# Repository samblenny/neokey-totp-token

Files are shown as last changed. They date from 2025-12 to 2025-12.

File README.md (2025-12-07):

<!-- SPDX-License-Identifier: MIT -->
<!-- SPDX-FileCopyrightText: Copyright 2025 Sam Blenny -->
# NeoKey TOTP Token



This is a two factor authentication token to generate TOTP login codes for up
to four accounts. You can select which account by pressing a key on the 4-key
NeoKey keypad. The design is intended for desktop use in a safe location (wall
power + no worries of physical tampering) but where you do want to prevent
secrets from leaking over the network due to mis-configured cloud-sync backup
features or whatever.

Design Goals and Features:

1. Make the codes really easy to read and type, even in low light, by using a
   dimmable backlit TFT display with a relatively large font.

2. Support 4 TOTP account slots (one for each key of a 4-key NeoKey keypad).

3. The NeoPixel under the key for the currently selected account slot lights
   up. Pressing a different key switches the selected account. Pressing the
   selected key a second time puts the token in standby mode (backlight and
   NeoPixels off).

4. Store secrets in an I2C EEPROM rather than in the CLUE board's flash. This
   makes it so the secrets aren't trivially accessible to a connected computer
   as USB mass storage files. This way, they won't get accidentally sucked into
   backups, and malware would have to work harder to access them.

5. Set DS3231 RTC time from the USB serial console by opening the REPL,
   importing the `util` module, then calling `util.set_time()`.

6. Add and manage TOTP accounts in the EEPROM's database of account slots by
   using similar REPL functions (`import util` then `util.menu()`).

7. Use the token fully airgapped after initial setup by powering it from a
   phone charger and reading codes off the TFT display.

## Hardware

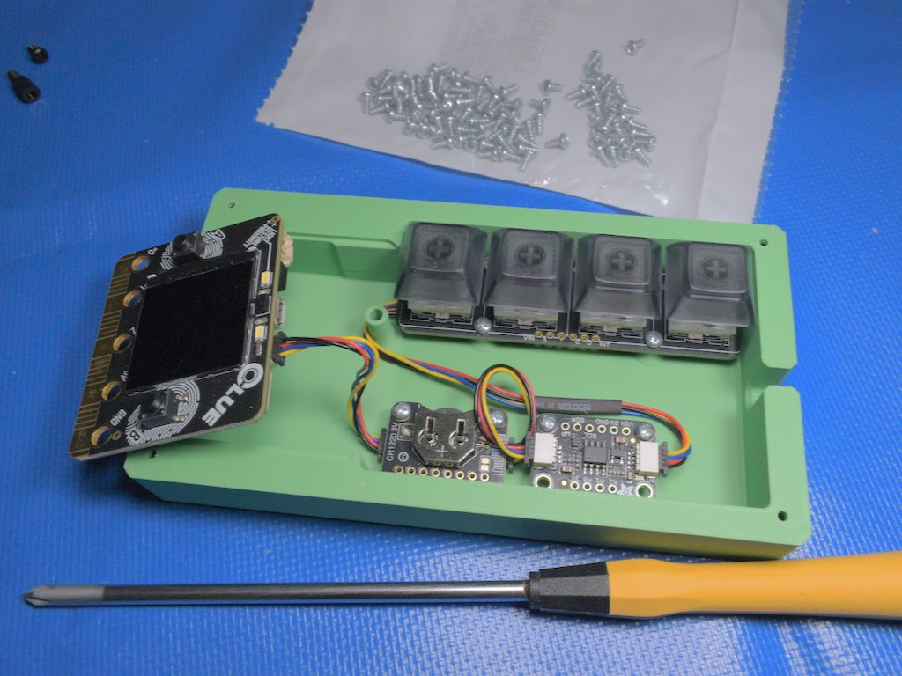
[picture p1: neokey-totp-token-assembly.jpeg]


The code here is written for:
- [Adafruit CLUE - nRF52840 Express](https://www.adafruit.com/product/4500)
- [Adafruit DS3231 Precision RTC](https://www.adafruit.com/product/5188)
- [Adafruit 24LC32 I2C EEPROM](https://www.adafruit.com/product/5146)
- [Adafruit NeoKey 1x4 QT I2C Mechanical Key Switches with NeoPixels](https://www.adafruit.com/product/4980)

Additional Parts:
- [Kailh Mechanical Key Switches Cherry MX Brown Compatible](https://www.adafruit.com/product/4954)
- [Translucent Smoke DSA Keycaps for MX Compatible Switches](https://www.adafruit.com/product/5008)
- [CR1220 3V Lithium Coin Cell Battery](https://www.adafruit.com/product/380)
- [STEMMA QT / Qwiic JST SH 4-Pin Cable - 50mm Long](https://www.adafruit.com/product/4399) (qty 2)
- [STEMMA QT / Qwiic JST SH 4-Pin Cable - 100mm Long](https://www.adafruit.com/product/4210) (qty 1)
- 2-28x3/16" Thread Rolling Screws (very short self tapping plastic screws)
- 2-28x1/4" Thread Rolling Screws (short self tapping plastic screws)

## 3D Printable Enclosure

The Blender design file and STL printable files for the enclosure are in the
[enclosure/](enclosure) directory.

To attach the I2C breakout boards to the base of the enclosure, use 2-28x3/16"
thread rolling screws. To attach the bezel to the base, use 2-28x1/4" thread
rolling screws.

## Install & Setup

You will need to:

1. Ensure your CLUE board has an [up to date bootloader](https://learn.adafruit.com/adafruit-clue/update-bootloader)

2. Download CircuitPython 10.0.3 .UF2 file from the circuitpython.org downloads
   page for
   [CLUE NRF52840 Express](https://circuitpython.org/board/clue_nrf52840_express/)

3. Follow Adafruit's
   [CircuitPython on CLUE](https://learn.adafruit.com/adafruit-clue/circuitpython)
   Learn guide to install CircuitPython: plug CLUE into a computer, double-click
   CLUE's reset button, wait for CLUEBOOT drive, drag UF2 file onto CLUEBOOT
   drive, wait for copy to finish.

4. Unplug the CLUE and assemble the rest of the hardware.

5. Get the project bundle from the release page and copy its code and library
   files from the 10.x directory to your board's `CIRCUITPY` drive.

## Set RTC Time in UTC

When you first install a battery in the DS3231, the time will be wildly wrong.
You can set the time from the REPL by importing the `util` module then calling
`util.set_time()`, like this:

```
Adafruit CircuitPython 10.0.3 on 2025-10-17; Adafruit CLUE nRF52840 Express with nRF52840
>>> import util
>>> util.now()
'2000-01-01 02:06:52'
>>> util.set_time()
Set DS3231 RTC time...
   year: 2025
  month: 11
    day: 25
   hour: 00
 minute: 01
seconds: 02
new RTC time:  2025-11-25 00:01:02
>>> # wait a while, then check the time
>>> util.get_time()
2025-11-25 00:06:02
>>>
```

When you set the time, use a GPS or NTP synchronized reference that shows UTC
time with seconds (e.g. https://samblenny.github.io/totp-util/clock/ ). Don't
set the clock according to your local timezone. You must use UTC.

Each of the "year:", "month:", "day:", etc. prompts come from python's
`input()` function. The text on the left is the input prompt shown by
`set_time()`, and the numbers on the right are an example of what you might
type for your response. When you hit return or enter for the seconds line, the
time will be set immediately.

## Store TOTP Accounts in EEPROM Database

The `util` module has several functions for managing the 4KB EEPROM as a
database of TOTP account details. You can enter QR code URIs with a 2D barcode
reader or by decoding elsewhere then copying and pasting. The EEPROM database
only stores a short (8 character) label and the 32 byte decoded seed (from the
`&secret=...` TOTP URI query parameter). The only supported options for
`&algorithm=`, `&digits=`, and `&period=` are SHA1, 6 digits, and 30 seconds.
That will work for many services that use TOTP. If you need something else, you
can modify the code.

To get started managing the EEPROM database, open the USB serial console and do
the Ctrl-C thing to get into the CircuitPython REPL. From there, import util
then call `util.menu()` to see what's available. The first time, you will need
to format the EEPROM. After that, you can add, erase, or copy accounts as you
like. There are 4 available slots (one for each key of a 4-key NeoKey keypad).

This is an example of how it looks to use the menu and provision two demo
accounts (I used a USB 2D barcode reader to type the otpauth URIs):

```
>>> import util
>>> util.menu()
Available functions:

 1. add_totp_account()    - Add a new TOTP account.
 2. copy_totp_account()   - Copy a TOTP account to another slot.
 3. erase_totp_account()  - Erase a TOTP account from EEPROM.
 4. format_eeprom()       - Format the EEPROM for TOTP storage.
 5. get_time()            - Get the current DS3231 RTC time.
 6. list_totp_accounts()  - List all stored TOTP accounts.
 7. set_time()            - Set the DS3231 RTC time.

Choose a function by number (or Enter to cancel): 4
Are you sure? This will erase all data. (y/n): y
Writing header page...
Zeroing 127 pages:
................................................................
...............................................................
EEPROM formatted successfully.
>>> util.add_totp_account()
Enter slot number (1-4): 1
Enter label (max 8 chars): Alice
Enter TOTP URI: otpauth://totp/Example:alice@google.com?secret=JBSWY3DPEHPK3PXP&issuer=Example
Record added to slot 1.
>>> util.add_totp_account()
Enter slot number (1-4): 2
Enter label (max 8 chars): JohnDoe
Enter TOTP URI: otpauth://totp/ACME%20Co:john.doe@email.com?secret=HXDMVJECJJWSRB3HWIZR4IFUGFTMXBOZ&issuer=ACME%20Co&algorithm=SHA1&digits=6&period=30
Record added to slot 2.
>>> util.list_totp_accounts()
Slot 1: 'Alice'
Slot 2: 'JohnDoe'
Slot 3: -- empty --
Slot 4: -- empty --
>>>
```

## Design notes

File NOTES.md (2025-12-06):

# Notes

Related Learn Guides:
- https://learn.adafruit.com/circuitpython-display-text-library/types-of-labels
- https://learn.adafruit.com/adafruit-ds3231-precision-rtc-breakout
- https://learn.adafruit.com/adafruit-24lc32-i2c-eeprom-breakout-32kbit-4-kb
- https://learn.adafruit.com/neokey-1x4-qt-i2c (I2C 4 key keyboard)
- https://learn.adafruit.com/adafruit-1-3-and-1-54-240-x-240-wide-angle-tft-lcd-displays
  (CLUE 1.3" 240x240 ST7789 display)
- https://learn.adafruit.com/neokey-1x4-qt-i2c

Related API Docs:
- https://docs.circuitpython.org/en/latest/shared-bindings/atexit/
- https://docs.circuitpython.org/en/latest/shared-bindings/supervisor/
- https://docs.circuitpython.org/en/latest/shared-bindings/busio/#busio.SPI
- https://docs.circuitpython.org/projects/ds3231/en/stable/api.html
- https://docs.circuitpython.org/en/latest/shared-bindings/pwmio/

RFCs:
- [RFC 4226: HOTP](https://datatracker.ietf.org/doc/html/rfc4226)
- [RFC 6238: TOTP](https://datatracker.ietf.org/doc/html/rfc6238)

Pins provided by `import board`:
```
A0              A1              A2              A3
A4              A5              A6              A7
ACCELEROMETER_GYRO_INTERRUPT    BUTTON_A        BUTTON_B
D0              D1              D10             D11
D12             D13             D14             D15
D16             D17             D18             D19
D2              D20             D3              D4
D5              D6              D7              D8
D9              DISPLAY         I2C             L
LED             MICROPHONE_CLOCK                MICROPHONE_DATA
MISO            MOSI            NEOPIXEL        P0
P1              P10             P11             P12
P13             P14             P15             P16
P17             P18             P19             P2
P20             P3              P4              P5
P6              P7              P8              P9
PROXIMITY_LIGHT_INTERRUPT       RX              SCK
SCL             SDA             SPEAKER         SPI
STEMMA_I2C      TFT_BACKLIGHT   TFT_CS          TFT_DC
TFT_MOSI        TFT_RESET       TFT_SCK         TX
UART            WHITE_LEDS
```

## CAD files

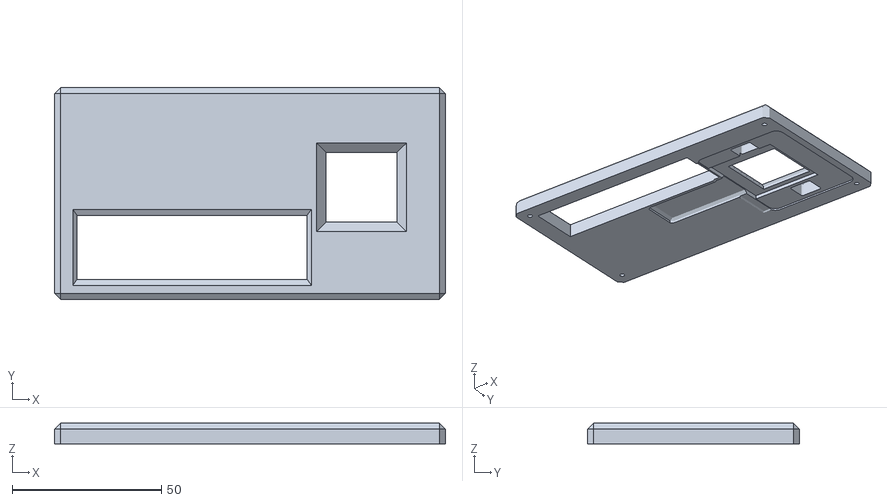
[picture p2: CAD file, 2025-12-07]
enclosure/neokey-clue-totp-bezel.stl
131.0 x 71.0 x 6.98

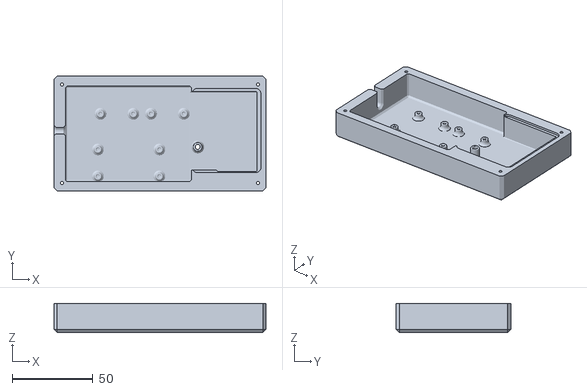
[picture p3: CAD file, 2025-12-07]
enclosure/neokey-clue-totp-base.stl
131.0 x 71.0 x 18.0

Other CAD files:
enclosure/neokey-clue-totp-nopcb.blend

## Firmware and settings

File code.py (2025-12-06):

# SPDX-License-Identifier: MIT
# SPDX-FileCopyrightText: Copyright 2025 Sam Blenny
#
# See NOTES.md for documentation links and pinout info.
#
import time

from controller import (Controller, NEOKEY0, NEOKEY1, NEOKEY2, NEOKEY3,
    NP_AMBER, NP_RED)


# The controller manages IO with I2C and SPI devices, and it keeps track of the
# EEPROM-backed database of TOTP accounts
ctrl = Controller()
ctrl.load_totp_accounts()


# These variables help with edge detection of changing values in the main loop
t = ctrl.datetime()
prev_t = t
prev_nk = ctrl.get_neokey_bits()
need_refresh = True

# Main loop
while True:

    # Is it time to update the TOTP code? (period over or refresh requested)
    if t.tm_sec % 30 == 0 or need_refresh:
        # Generate new totp code at multiples of 30 seconds
        unix_time = time.mktime(ctrl.datetime())
        slot, label, totp_code = ctrl.get_selected_totp(unix_time)
        code_changed = True

    # Redraw the display only when backlight is on
    if ctrl.bl_enable:
        seconds = t[5] % 30
        ctrl.set_text('%02d\n%s\n%s' % (seconds, label, totp_code))

    # Make sure the right NeoKey selected slot LED is lit
    for i in range(4):
        if i == ctrl.get_selected_slot():
            if ctrl.is_selected_slot_empty():
                ctrl.set_neokey(i, NP_RED)    # red for empty slots
            else:
                ctrl.set_neokey(i, NP_AMBER)  # amber for configured slots
        else:
            ctrl.set_neokey_off(i)

    # Clear the manual update requested flag
    need_refresh = False

    # Wait until second rolls over
    while t.tm_sec == prev_t.tm_sec and not need_refresh:

        # 1. Spend about 100ms polling for input events
        t_10Hz = time.monotonic() + 0.1
        while time.monotonic() < t_10Hz and not need_refresh:

            # Sleep to rate limit I2C, debounce buttons, do VM background tasks
            time.sleep(0.01)

            # Check the currently selected TOTP account slot
            slot = ctrl.get_selected_slot()

            # Monitor the 4 NeoKeys for state transitions
            nk = ctrl.get_neokey_bits()  # get bitfield of current key states
            diff = nk ^ prev_nk          # use XOR to find which bits changed
            prev_nk = nk                 # update previous values for next loop

            # Did any key get pressed while backlight was off?
            waking_up = False
            if (diff & nk) and not ctrl.bl_enable:
                # Rising edge of key press -> wake up the screen
                ctrl.backlight_on()
                need_refresh = True
                waking_up = True  # don't go back to sleep when key released

            # Check for key press to select TOTP account slots. When the
            # currently selected key is pressed, turn off the display. When a
            # different key is pressed, select the slot for that key.
            for i, bitmask in enumerate((NEOKEY0, NEOKEY1, NEOKEY2, NEOKEY3)):
                if diff & bitmask and ctrl.bl_enable:
                    # Check if other keys were already down to avoid potential
                    # weird glitchy behavior if you fat-finger multiple keys at
                    # the same time
                    other_keys_pressed = bool(nk & (~bitmask))
                    if nk & bitmask and not other_keys_pressed:
                        # Key was just pressed
                        if slot == i:
                            # Slot was already selected (toggle backlight?)
                            if not waking_up:
                                ctrl.backlight_off()
                                ctrl.set_neokey_off(i)
                        else:
                            # Slot wasn't selected -> select it
                            if ctrl.select_account(i):
                                # Selected a non-empty slot
                                ctrl.set_neokey(i, NP_AMBER)
                                need_refresh = True
                            else:
                                # Empty slot
                                ctrl.set_neokey(i, NP_RED)
                                need_refresh = True
                    else:
                        # Key released or other keys were already pressed
                        pass

            # -- END of input polling loop --


        # 2. Poll RTC at about 10 Hz to detect when seconds have changed
        if ctrl.bl_enable:
            t = ctrl.datetime()

    # After the seconds have changed, update the previous time
    prev_t = t

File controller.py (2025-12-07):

# SPDX-License-Identifier: MIT
# SPDX-FileCopyrightText: Copyright 2025 Sam Blenny
#
# See NOTES.md for documentation links and pinout info.
#
import atexit
import board
import busio
import collections
import digitalio
import displayio
from fourwire import FourWire
import gc
from micropython import const
from pwmio import PWMOut
import os
import terminalio


from adafruit_24lc32 import EEPROM_I2C
from adafruit_display_text import label
from adafruit_ds3231 import DS3231
from adafruit_neokey.neokey1x4 import NeoKey1x4
from adafruit_st7789 import ST7789

from eeprom_db import check_eeprom_format, is_slot_in_use, load_totp_account
from sb_totp import base32_encode, totp_sha1


# Begin TFT backlight dimming (100% brightness is PWM duty_cycle=0xffff)
BACKLIGHT_ON = const(26214)  # 40% of 0xffff
BACKLIGHT_OFF = const(0)

# NeoKey keypress bitfield constants
NEOKEY0 = const(1)
NEOKEY1 = const(2)
NEOKEY2 = const(4)
NEOKEY3 = const(8)

# NeoKey NeoPixel color constants
NP_AMBER = const(0x202000)
NP_RED   = const(0x400000)
NP_OFF   = const(0)


class Controller:

    def __init__(self):
        # I2C RTC, EEPROM, and NeoKey
        i2c = busio.I2C(board.SCL, board.SDA, frequency=250_000)
        self.i2c = i2c
        self.rtc = DS3231(i2c)
        self.neokey = NeoKey1x4(i2c, addr=0x30)
        self.eeprom = EEPROM_I2C(i2c)
        self.accounts = []                            # TOTP account slot data
        self.selected_acct = None

        # Display backlight PWM dimming
        self.backlight = PWMOut(board.TFT_BACKLIGHT, frequency=500,
            duty_cycle=BACKLIGHT_ON)
        self.bl_enable = True

        # CLUE 240x240 ST7789 TFT Display
        displayio.release_displays()
        gc.collect()
        spi = busio.SPI(board.TFT_SCK, MOSI=board.TFT_MOSI)
        display_bus = FourWire(spi, command=board.TFT_DC,
            chip_select=board.TFT_CS, reset=board.TFT_RESET)
        display = ST7789(display_bus, width=240, height=240, rowstart=80,
            bgr=True, rotation=0, auto_refresh=False)
        group = displayio.Group()
        display.root_group = group
        display.refresh()
        textbox = label.Label(font=terminalio.FONT, scale=4, color=0xefef00)
        textbox.anchor_point = (0, 0)
        textbox.anchored_position = (16, 8)
        textbox.line_spacing = 1.25  # default is 1.25
        group.append(textbox)
        self.spi = spi
        self.display_bus = display_bus
        self.display = display
        self.group = group
        self.textbox = textbox

        # Set an atexit handler to release the display once code.py ends. This
        # is an aesthetic filter to prevent CircuitPython's supervisor from
        # hijacking the display to show noisy stuff I don't want to see.
        def atexit_shutdown_display():
            try:
                self.set_text('OFFLINE')
                displayio.release_displays()
                self.spi.deinit()
                for i in range(4):
                    self.neokey.pixels[i] = 0
            except AttributeError:
                pass
        atexit.register(atexit_shutdown_display)


    def backlight_off(self):
        self.backlight.duty_cycle = BACKLIGHT_OFF
        self.bl_enable = False
        self.set_text('')
        # Also make sure NeoKey NeoPixels are off
        for i in range(4):
            self.set_neokey_off(i)

    def backlight_on(self):
        self.backlight.duty_cycle = BACKLIGHT_ON
        self.bl_enable = True

    def set_text(self, txt):
        self.textbox.text = txt
        self.display.refresh()

    def load_totp_accounts(self):
        # Load TOTP account slot data from EEPROM database
        TOTPAccount = collections.namedtuple("TOTPAccount",
            ["slot", "label", "secret_b32"])
        try:
            eeprom = self.eeprom
            check_eeprom_format(eeprom)
            first_used_index = None
            for slot in range(1, 5):
                if is_slot_in_use(eeprom, slot):
                    label, secret_bytes = load_totp_account(eeprom, slot)
                    secret_b32 = base32_encode(secret_bytes)
                    self.accounts.append(TOTPAccount(slot, label, secret_b32))
                    if first_used_index is None:
                        first_used_index = slot-1
                else:
                    self.accounts.append(None)
            self.selected_acct = first_used_index
        except ValueError as e:
            print(e)

        # Print summary from loading the EEPROM account database
        print('Loaded data for %d TOTP account slots from EEPROM' % (
            len(self.accounts)))
        for i, a in enumerate(self.accounts):
            if a is None:
                print(" slot %d: -- empty --")
            else:
                print(" slot %d: '%s'" % (a.slot, a.label))
        if self.selected_acct is not None:
            print("Selected Slot:", self.accounts[self.selected_acct].slot)

    def select_account(self, slot):
        # Try to select requested slot (return False for empty slot)
        if (0 <= slot < len(self.accounts)):
            self.selected_acct = slot
        else:
            raise ValueError(f"slot number out of range: {slot}")

        if self.accounts[self.selected_acct] is None:
            # This slot is empty
            return False
        # Happy path: slot is configured with an account
        return True

    def get_selected_slot(self):
        return self.selected_acct

    def is_selected_slot_empty(self):
        # Return True if there's no account configured for the selected slot
        return self.accounts[self.selected_acct] is None

    def get_selected_totp(self, unix_time):
        # Get TOTP slot, label, and code for the selected account
        if self.selected_acct is None:
            return ('', '', '')
        acct = self.accounts[self.selected_acct]
        if acct is None:
            return ('', 'empty', '')
        # CAUTION! For boards that use adafruit_hashlib.hashlib for SHA1, this
        # call may take on the order of 2 seconds to finish
        code = totp_sha1(acct.secret_b32, unix_time, digits=6, period=30)
        return (acct.slot, acct.label, code)

    def datetime(self):
        return self.rtc.datetime

    def get_neokey_bits(self):
        # Convert the list of booleans from NeoKey1x4 to an integer bitfield so
        # it's easier to detect state changes using XOR and AND
        k = self.neokey.get_keys()
        return (NEOKEY0 * int(k[0]) + NEOKEY1 * int(k[1]) + NEOKEY2 * int(k[2])
            + NEOKEY3 * int(k[3]))

    def set_neokey(self, key, color):
        self.neokey.pixels[key] = color

    def set_neokey_off(self, key):
        self.neokey.pixels[key] = NP_OFF

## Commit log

2025-11-25 hand wave to toggle display backlight
    This uses the CLUE's proximity sensor to toggle the display
    backlight on the rising edge of a proximity event. If you wave your
    hand over the CLUE, it toggles the backlight. It's like magic.
    I plan to use this to enable/disable TOTP code generation.
2025-11-26 add function to copy totp account between slots
2025-11-26 refactor util.py
    This factors out repeated boilerplate for managing totp account
    slots in the eeprom database.
2025-11-28 fix TOTP refresh on backlight enable
    Make sure that the TOTP code gets refreshed immediately when the
    backlight gets turned back on after being in standby mode.
    [code.py]
2025-12-06 overhaul code for NeoKey input
    Lots of Changes:
    - Get rid of light sensor and CLUE button input
    - Implement NeoKey input
    - Reduce account slots from 15 to 4 so there's a one to one mapping
    from the 4 NeoKey keys to the 4 account slots
    - Shorten time display to just seconds modulo 30
    - Implement a new backlight switching scheme using the NeoKeys
    instead of the light sensor
    [bundle_manifest.cfg]
2025-12-06 fix edge case keypress glitches
    This makes it so it's harder to trigger glitching by fat-fingering
    more than one key at the same time. Previously, pressing two keys
    at once would often leave a NeoPixel turned on after the backlight
    turned off.
    [code.py, controller.py]
2025-12-07 3d printable enclosure .blend & .stl
    [neokey-clue-totp-base.stl, neokey-clue-totp-bezel.stl, neokey-clue-totp-nopcb.blend]
2025-12-07 Use brighter NeoPixel color constants
    Now that the enclosure blocks glare that used to leak out the side
    of the NeoKeys, it looks better to use brighter colors. The light
    only comes through the keycaps now.
    [controller.py]
2025-12-07 add some margin around the text
    The bezel on the new enclosure comes pretty close to the edge of
    the screen's active area, so the text looks better with a small
    margin around it.
2025-12-07 add assembly photo, readme edits
